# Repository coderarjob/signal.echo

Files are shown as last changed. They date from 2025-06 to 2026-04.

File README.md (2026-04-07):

<p align="center">
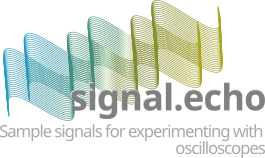
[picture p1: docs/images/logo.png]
    
    <br/>
    <br/>
    
    
</p>

## About

This is a hardware project based on Atmega8A microcontroller. This project came about from a
personal need for a demo board to test my new oscilloscope. I plan to create a complete PCB
along with firmware in this repo.

**Caution**: The `master` branch contains changes for the upcoming version and may not always be
stable. If you wish to manufacture, use the latest `release/version_x.x` branch or one of the
[released](https://github.com/coderarjob/signal.echo/releases) versions.

See [LICENCE](./LICENSE) for terms under which this project is released and developed.

### Screenshots

##### 1. Serial RS232 (TTL Level) decoding test

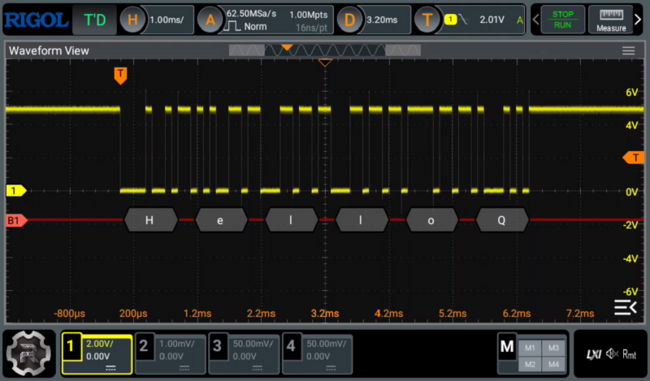
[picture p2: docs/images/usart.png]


##### 2. Serial I2C decoding test

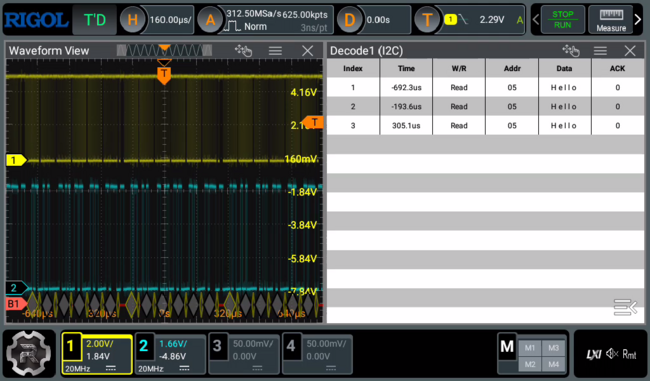
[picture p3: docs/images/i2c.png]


##### 3. Positive & negative Runt detection pulse

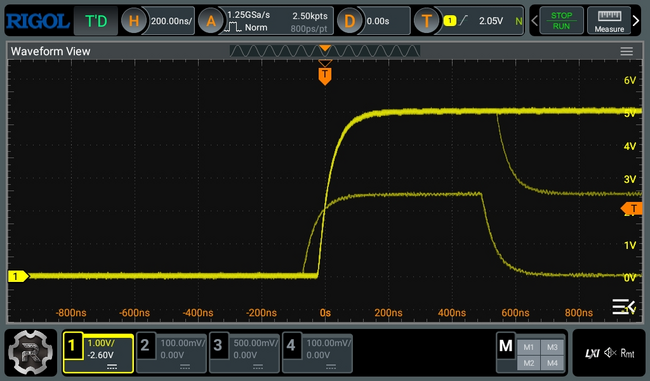
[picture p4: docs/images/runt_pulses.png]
Runt pulse


##### 4. Burst pulses (long delay)

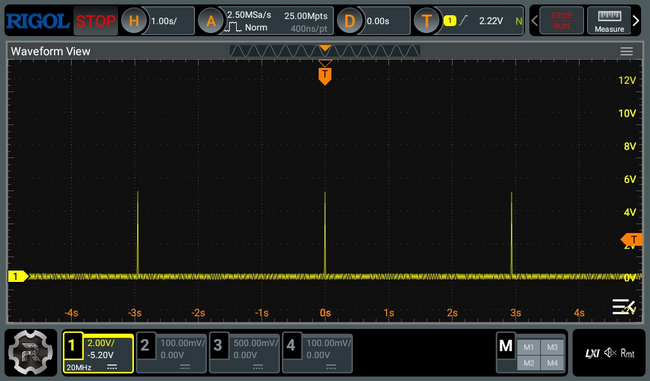
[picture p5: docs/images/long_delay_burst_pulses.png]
Burst pulse


##### 5. Two burst (time coorolated) pulses

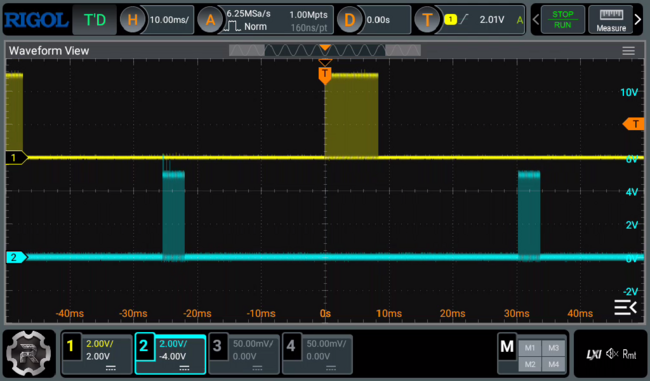
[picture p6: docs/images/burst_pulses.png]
two burst pulse


##### 6. Sine wave

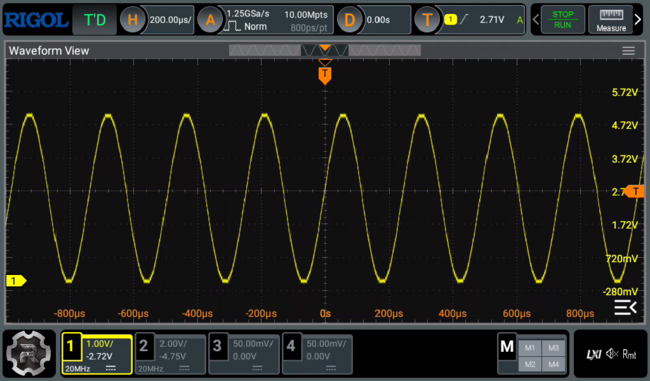
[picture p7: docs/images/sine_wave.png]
Sine wave

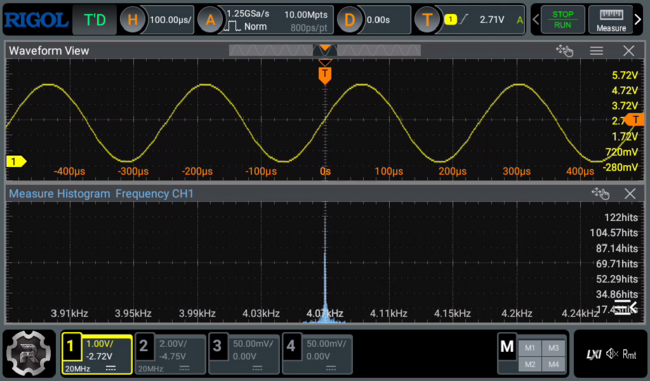
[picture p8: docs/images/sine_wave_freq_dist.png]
Sine wave

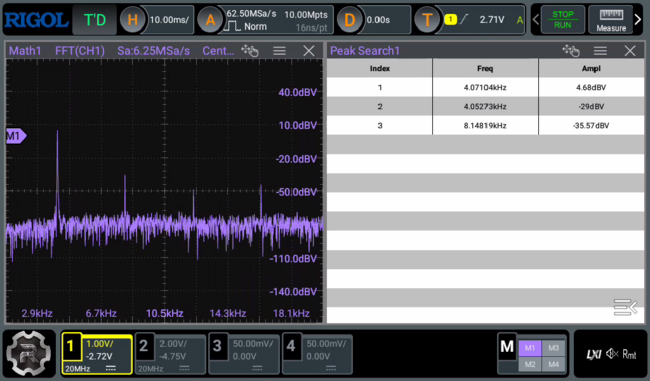
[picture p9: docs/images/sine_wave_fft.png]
Sine wave


##### 7. Amplitude Modulation wave

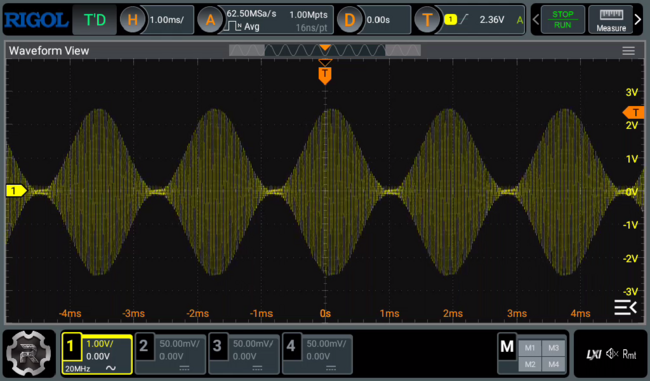
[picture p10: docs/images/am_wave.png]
Sine wave

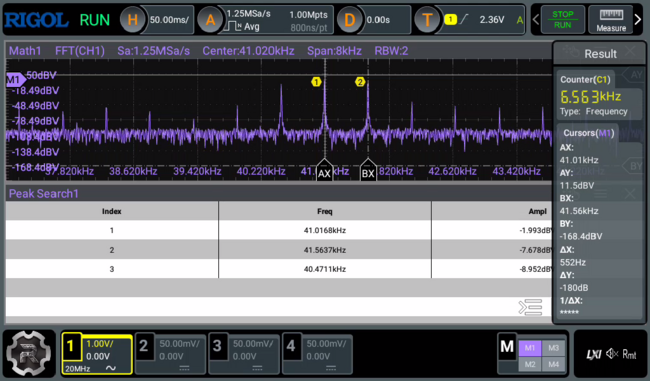
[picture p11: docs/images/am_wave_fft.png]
Sine wave


##### 8. Triangle wave

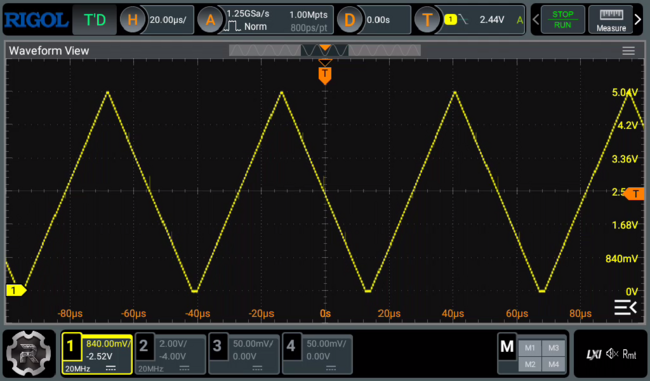
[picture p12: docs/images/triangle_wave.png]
Triangle wave

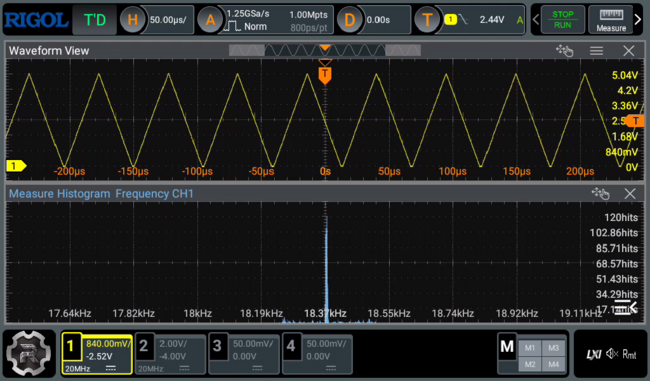
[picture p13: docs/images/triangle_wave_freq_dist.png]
Triangle wave

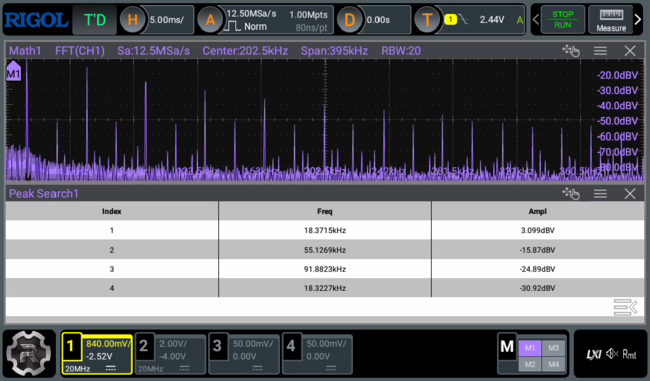
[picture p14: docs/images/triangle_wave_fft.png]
Triangle wave


##### 9. Sawtooth wave

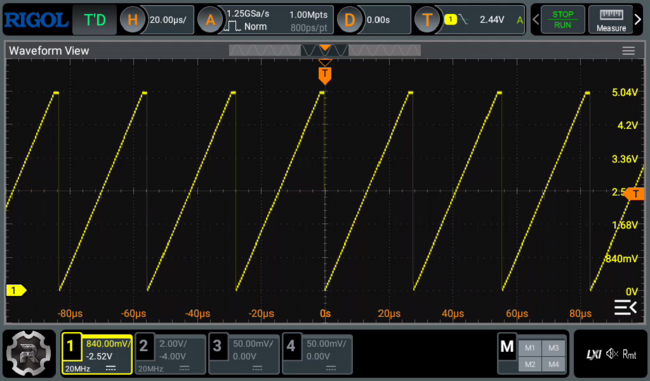
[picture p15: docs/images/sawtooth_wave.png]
Sawtooth wave

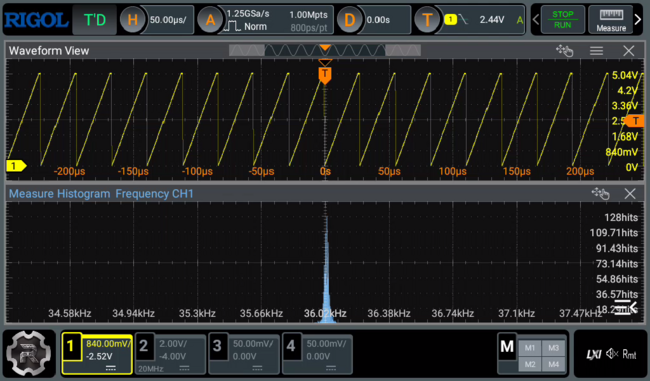
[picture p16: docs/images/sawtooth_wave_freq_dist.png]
Sawtooth wave

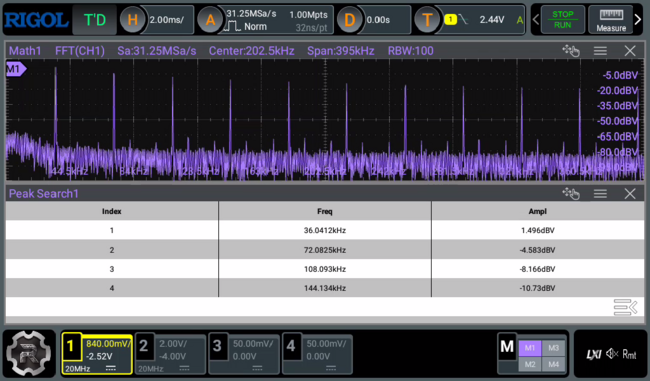
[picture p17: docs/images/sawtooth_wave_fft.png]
Sawtooth wave


### Goals

- [X] Firmware: RS232 sample output (positive)
- [X] Firmware: I2C sample output
- [X] Firmware: Runt pulse (+ve & -ve runt pulses)
- [X] Firmware: Sine wave pattern
- [X] Firmware: Amplitude Modulation wave pattern
- [X] Firmware: Triangle wave pattern
- [X] Firmware: Sawtooth wave pattern
- [X] Firmware: Burst data in two lines
- [X] Firmware: Separate arch independent codes
- [X] Unittests: Add unittests for utils
- [X] Unittests: Add unittests for existing tests
- [X] Manufacturing: Build the PCB board

## Building prerequisites

1. Requires Linux environment for building.
2. GNU Make
3. avr-gcc
4. avr-libc

### Firmware

Build the firmware using the following command. Firmware binary is the `./out/firmware.hex` file.

```bash
BUILD_DIR=out make
```

To program using avrdude we run the following command.

```bash
make program
```

When programming a new microcontroller, we also need to program the required fuse bits. This can be
using the following command

```bash
make program_fuses
```

### Unittests

We can build every unittests and run them using the `run` target.

```bash
BUILD=ut BUILD_DIR=out/ut make run
```

### Tools

Some tools which are used exclusively in this project are/will be put into the `tools` folder. Each
may have different prerequisites and build procedures. For information see `Readme.md` of each
tool.

# Feedback

Open a GitHub issue or drop a email at arjobmukherjee@gmail.com. I would love to hear your
suggestions and feedbacks.

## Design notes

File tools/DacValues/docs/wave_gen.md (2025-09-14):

##### 14-August-2025 19:44:42
# Generation of waves using DAC
##### Tags: electronics

The microcontoller is indexing into an array of values and writes them to DAC. The timing between
each writes is not controlled but can be taken as constant. Say the aray contains values that
represent one cycle of a sine wave. When these are written out, the frequency of the resulting
waveform will depend on two things:
1. `T` - The time spent by the microcontoller between writing two consecutive values to the DAC.
2. `N` - Number of values that represent the one cycle. If there are more number of points/values
   then it will take more time to dump the whole array to the DAC. Thus (frequency of the
   wave) `f ~ 1/(T * N)`.

The above relation of `f` & `N` means that a fast waveform requires less number of points but
also for the same reason will look bad because of the large quantization steps. This will be played
with depending on what waveform is generated.

All this happens in the microcontoller side and as you can see it just dumps data into the DAC and
does not control either the frequency or the look of it. Both depends on the how the values are
generated.

### Generation of DAC data - Sine wave

As stated above the DAC values given to the microcontoller represent one cycle of the required
waveform (one cycle all that is required because the waveform is repeating). If we want to increase
frequency, less points will represent that cycle, and a nicer looking waveform (but lower frequency)
will have more points for the same cycle.

Take the example of sine wave generation:

#### Algorithm

`sine(freq_scale, sample_count)` where 

* `freq_scale` - Number of generated points (samples) will be decreased to increase frequency by
  this amount
* `sample_count` - This many points will make one cycle of the repeating waveform, when `freq_scale`
  is 1.

```c
sine(freq_scale, sample_count) {
    // Time is incremented by this amount in each iteration.
    dt = freq_scale / sample_count
    
    // Since we stop iterating when time of 1.0 is reached, the number of samples that will be
    // in the output by then is 1/dt or `sample_count/freq_scale` number of points. That is as
    // `freq_scale` increases, N decreases and vice-versa.
    // Also note we have reached full cylcle (2 * PI radians) when time reached 1.0.
    N = 1/dt
    
    // Output list
    List(f64) output = empty;
    for (t = 0; t < 1.0; t += dt) {
        output.add(sin(2 * PI * t))
    }
    
    return output
}
```

#### Explanation

After `N = 1/dt` iterations, we will have `t = N * dt => t = dt/dt = 1`. In other words after `N`
iterations we have
* Number of cycles: 1
* Number of radians traversed: `2 * PI`.
* Number of sample points: `sample_count/freq_scale`.

So in the end, if `freq_scale` is 1, output represents one cycle and will have `sample_count` number
of points. If `freq_scale` is 2, output still will represent one cycle but now will have
`sample_count/2` number of points. Less number of points to equates to faster dump thus more
frequency.

##### Why not use `sin(2 * PI * freq_scale * t)` instead?

Lets do the same calculation as above. Since `freq_scale` now moved to the sine function, `dt`
becomes `dt = 1.0 / sample_count`. After `N = 1/dt` iterations, we will have `t = N * dt => t =
dt/dt = 1`. This remains the same, but the outcome is different. So  after `N` iterations we have
* Number of cycles: `freq_scale`. If it is 1, then 1 cycle, if its 2 then 2 cycles and so on.
* Number of radians traversed: `2 * PI * freq_scale`.
* Number of sample points: `sample_count`

So in the end, if `freq_scale` is 1, like before output represents one cycle and will have
`sample_count` number of points. If however `freq_scale` is 2, output will instead represent 2
cycles but will still have `sample_count` number of points. Same number of points representing more
number of cycles means less number of points per cycle and thus like before this equates to faster
dump thus more frequency.

So now that we know the difference between the two ways, the former method is chosen for generating
sine wave, since it always output one single cycle, which is what we want.

### Generation of DAC data - AM wave

Much of the things remain the same, however there are a few more parameters which we need to know
about. Lets recap the parameters which are common and the new ones

1. Number of sample points: `sample_count`
2. Number of cycles per envelop eye: $n = BASE\_FREQ * freq\_scale$. Where `BASE_FREQ` is any constant,
   currently its `50`.
3. Number of sample points per cycle: $S = sample\_count/n$. This many samples points will make up
   each cycle of the carrier wave. Larger `S` makes up for a smoother wave with less prominent
   steps. Note that this has nothing to do the DAC width. Its the number of sample points not the
   max value of it.

In order to control both the carrier frequency and the signal frequency a relation need to be made
between them and the number of sample points.

We know that the total number of samples (`sample_count`) determines the signal frequency, so it can
be said

* $sample\_count \propto t_m$ where $t_m$ is the time period of the signal wave.
* $sample\_count \propto n * t_c$ where $n$ is as defined above and $t_c$ is the time period of the
  carrier wave.
* Thus $t_m = n * t_c$ <br/>
  or ${t_m/t_c} = n$ <br/>
  or ${f_c/f_m} = n$ where $f_c$ & $f_m$ are carrier frequency & signal frequency respectively.

This above relation makes it possible to change one frequency by keeping the other fixed and varying
$n$. For example in order to increase the signal frequency for some carrier frequency, we have to
decreases $n$.

From a general understanding the following relation between the frequencies and sample count can be
established.

* $f_c \propto 1/S$. Less number of points in one cycle of the carrier wave, more it the resulting
  frequency of the wave. This implies the following
* $f_c \propto n$. Less number of cycles per envelop eye, more is the carrier frequency.
* $f_m \propto 1/sample\_count$. Less is the total number of points, more is the overall frequency
  and thus the envelop/signal frequency.

Now that the theory is done, lets look at the algorithm

#### Algorithm

`am(freq_scale, sample_count)` where 

* `freq_scale` - Used to calculate the number of complete cycles in one envelop eye ($n$ as above).
* `sample_count` - Total number of points in one envelop eye. Unlike the sine wave case here we will
  always produce this many samples irrespective of the `freq_scale` value.

```c
am(freq_scale, sample_count) {
    // Time is incremented by this amount in each iteration.
    // This implies that `sample_count` number of points will be in output when time of 1.0 is
    // reached (where we stop).
    dt = 1.0 / sample_count
    
    // BASE_FREQ is a constant. When freq_scale is 1, n = BASE_FREQ. That is when freq_scale = 1,
    // `BASE_FREQ` number of complete cycles (of carrier wave) will be outputted.
    BASE_FREQ = 50
    n = BASE_FREQ * freq_scale
    
    // Output list
    List(f64) output = empty;
    for (t = 0; t < 1.0; t += dt) {
        // * The 0.5 multiplication is to keep the result of the following equation between 0 and 1.
        //   Without it the output is between 0 and 2. See below
        // * Phase shift of (PI / 2) is applied just to reposition the generated wave. See below.
        output.add((1 + sin(2 * PI * t - (PI / 2)) * 0.5 * cos(2 * PI * t * n)
    }
    
    return output
}
```

The below image shows the modulated wave and the carrier wave.

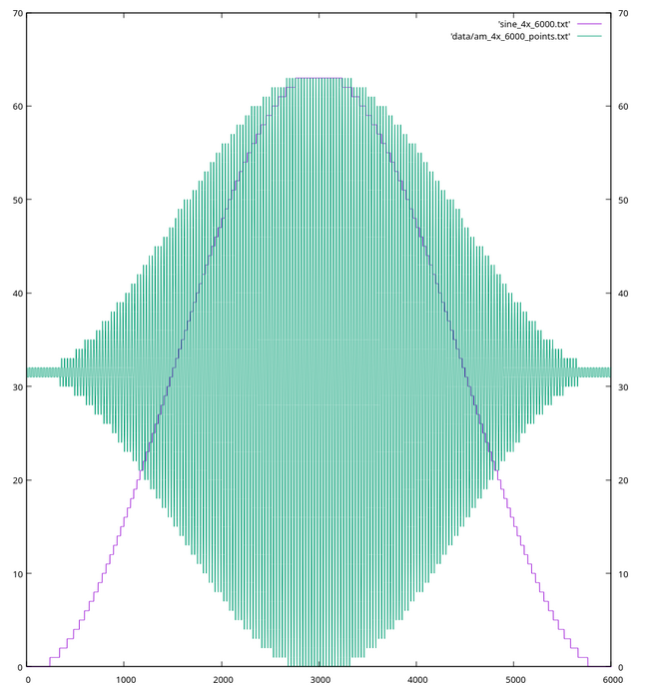
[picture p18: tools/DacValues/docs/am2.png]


* Note that one modulated eye is one full cycle of the signal not half cycle. Below image make it
  more clear.

For as an FYI the below image shows the same but without the phase shift of $\pi/2$ applied.
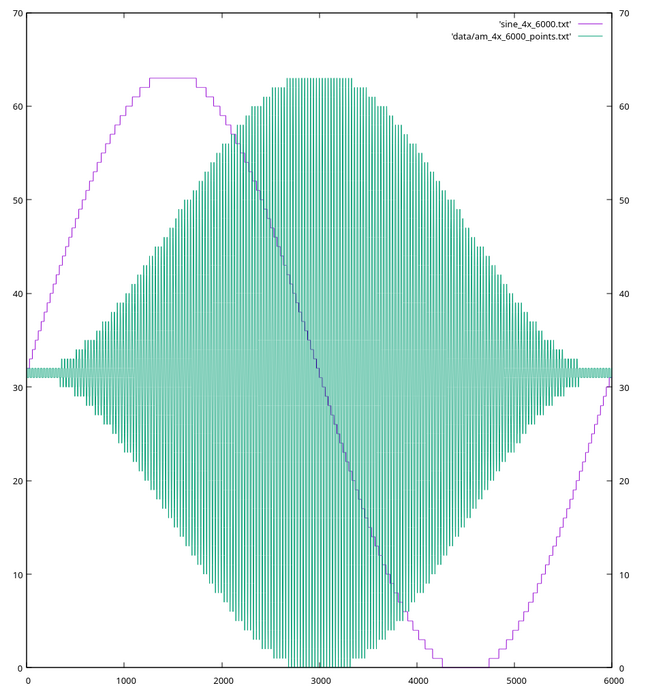
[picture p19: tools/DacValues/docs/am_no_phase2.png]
am_wave_with_phase_shift


#### Expectations

After `N = 1/dt` iterations, we will have `t = N * dt => t = dt/dt = 1`. In other words after `N`
iterations we have
* Number of cycles (signal wave): `1`
* Number of cycles (carrier wave) (`n`): `freq_scale * BASE_FREQ`
* Number of sample points: `sample_count`
* Number of samples per carrier wave cycle (`S`): $sample\_count/n$.

Note that this is exactly what other (alternate) method described in the Sine wave generation
section.

#### How to increase $f_m$ while keeping the $f_c$ and $S$ same?

Lets assume the following is AM wave we have currently:
```
* n             = 200. i.e freq_scale = 4 for BASE_FREQ = 50.
* fc / fm       = 200
* sample_count  = 6000
* S             = sample_count / n = 30

Actual frequency seen:
* fc = 41E3 Hz
* fm = 204  Hz
```

Now lets see what it takes to make systematic changes such as to increase the signal frequency while
keeping the look and feel same (carrier frequency and number of points per carrier wave cycle).

Its mentioned above that $f_m \propto 1/sample\_count$. Therefore to increase $f_m$, we have to
decrease $sample\_count$. However since $S = sample\_count/n$, in order to keep $S$ constant we have
to also decrease $n$.

Lets start by decreasing `n` first. Recall that `n` is the number of carrier cycles per envelop eye.
This will result in a higher `S`, so requires `sample_count` to also be lowered in order to keep `S`
constant.  Here `n` is decreased from 200 to 75. This is what is shown below.

```
* n            = 75 (our choice)
* S            = 30  (same as before)
* sample_count = S * n
               = 30 * 75 = 2250
* fc / fm      = 75 (from equation)
```

To generate the above/required AM wave we have call `am` function with the following parameters.
* `sample_count` = 2250
* `freq_scale`   = ${n \over BASE\_FREQ}$ = ${75 \over 50} = 1.5$.

```
Actual frequency seen

* fc = 41E3 Hz
* fm = 540  Hz
```

-------------------------

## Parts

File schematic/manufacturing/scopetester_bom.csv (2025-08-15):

Id | Designator | Footprint | Quantity | Designation | Supplier and ref
1 | J3 | PinHeader_2x05_P2.54mm_Vertical | 1 | AVR_ISP
2 | U1 | DIP-28_W7.62mm | 1 | ATmega8A-P
3 | C6,C7,C1,C2 | C_Disc_D3.0mm_W1.6mm_P2.50mm | 4 | 100nF
4 | JP1 | R_Axial_DIN0207_L6.3mm_D2.5mm_P7.62mm_Horizontal | 1 | Jumper_2_Bridged
5 | R8,R5,R9,R23,R12,R21,R18,R3,R6,R19,R16,R20,R7,R11,R14,R13,R15,R24,R4,R22,R2,R10,R17 | R_Axial_DIN0207_L6.3mm_D2.5mm_P7.62mm_Horizontal | 23 | 2.2k
6 | D1,D3,D4,D2 | LED_D3.0mm | 4 | LED_Small
7 | Y1 | Crystal_HC49-4H_Vertical | 1 | 16MHz
8 | SW1 | SW_PUSH_6mm_H4.3mm | 1 | SW_Push
9 | J2 | PinHeader_1x04_P2.54mm_Vertical | 1 | Conn_01x04
10 | C5 | CP_Radial_D5.0mm_P2.50mm | 1 | 1uF
11 | R1 | R_Axial_DIN0207_L6.3mm_D2.5mm_P7.62mm_Horizontal | 1 | 10k
12 | C4,C3 | C_Disc_D3.0mm_W1.6mm_P2.50mm | 2 | 22pF
13 | J1 | PinHeader_1x02_P2.54mm_Vertical | 1 | CON_PWR

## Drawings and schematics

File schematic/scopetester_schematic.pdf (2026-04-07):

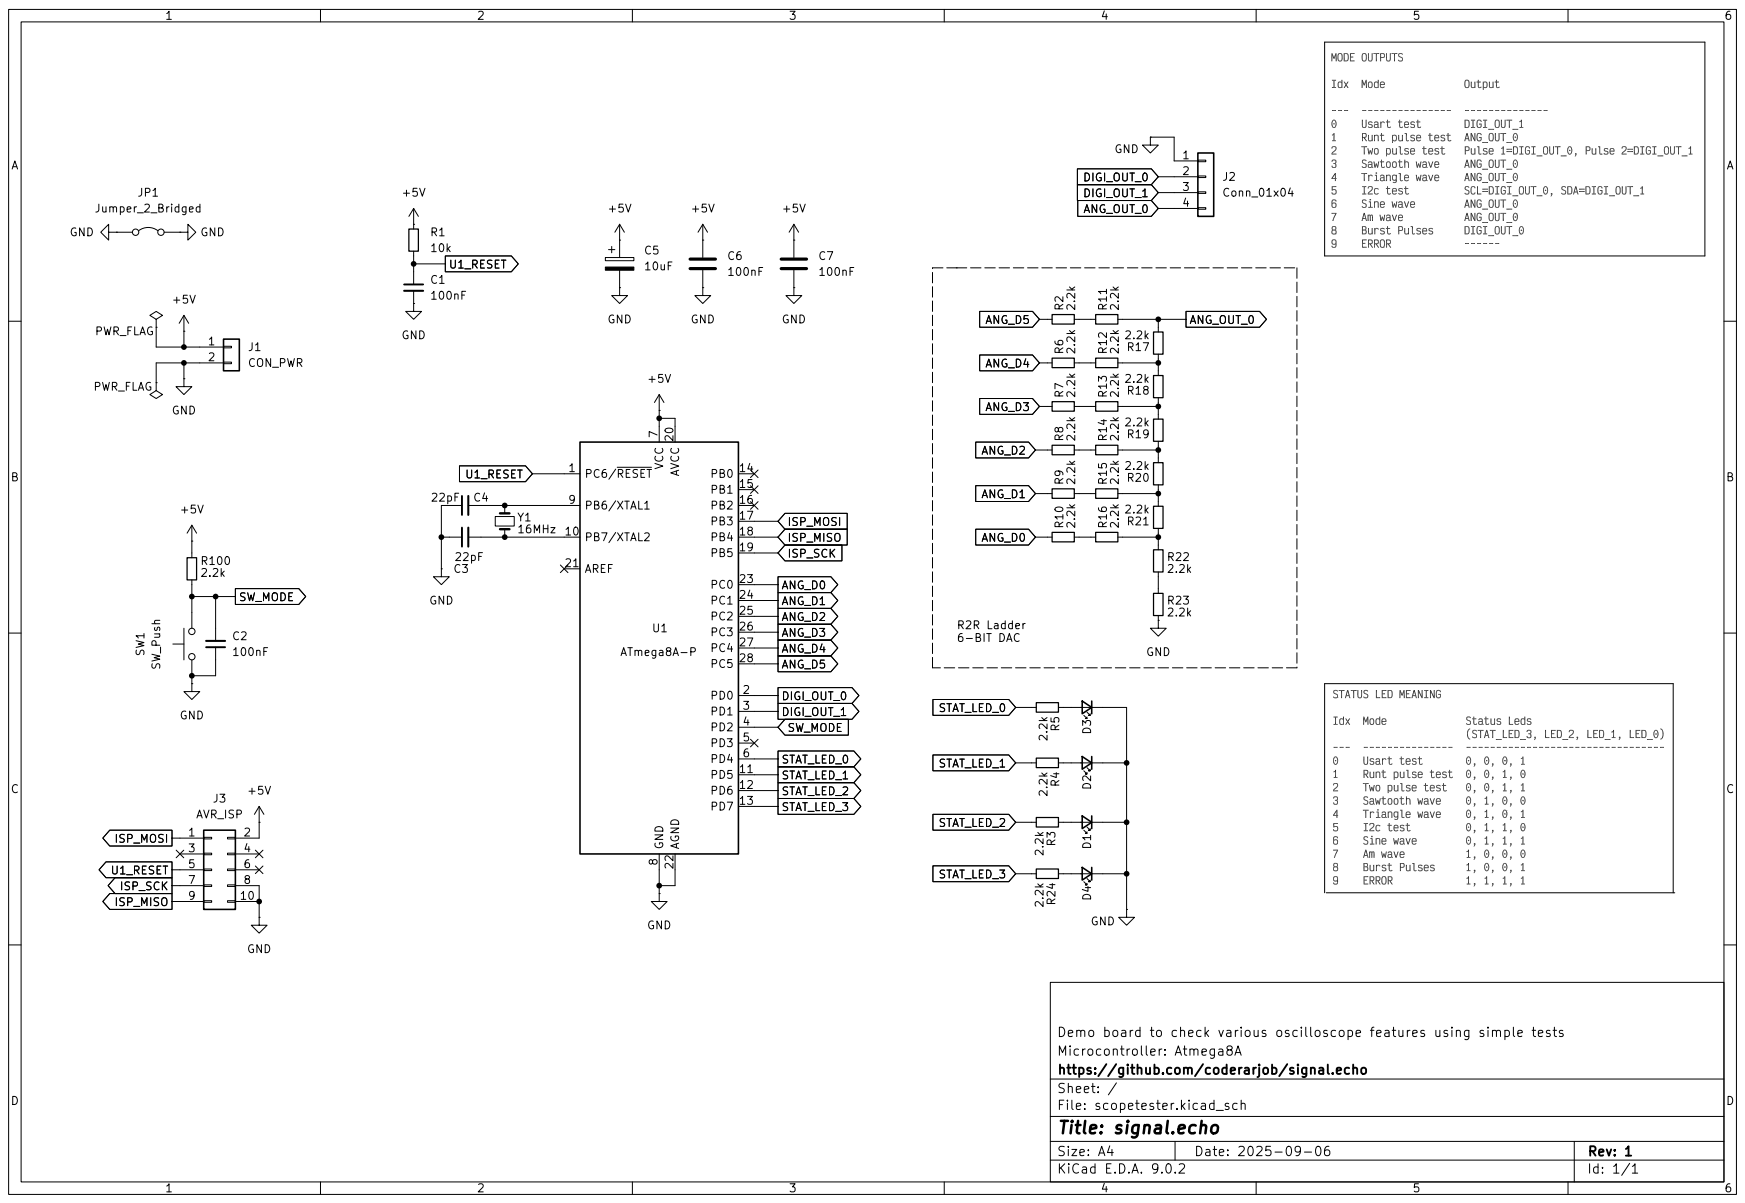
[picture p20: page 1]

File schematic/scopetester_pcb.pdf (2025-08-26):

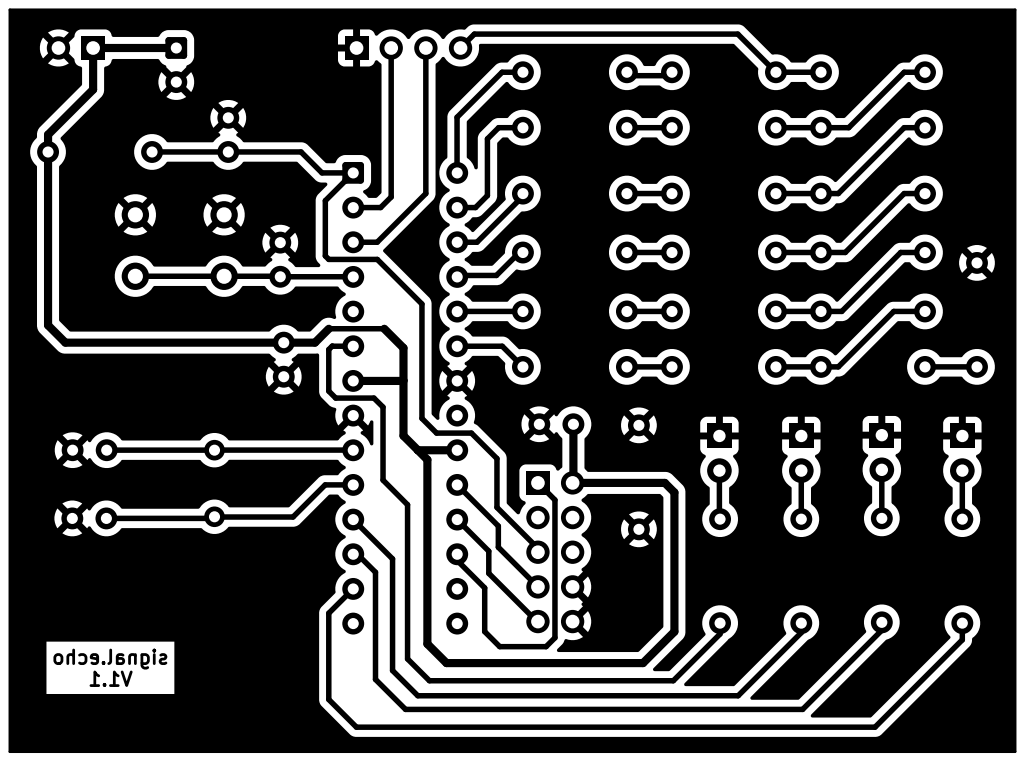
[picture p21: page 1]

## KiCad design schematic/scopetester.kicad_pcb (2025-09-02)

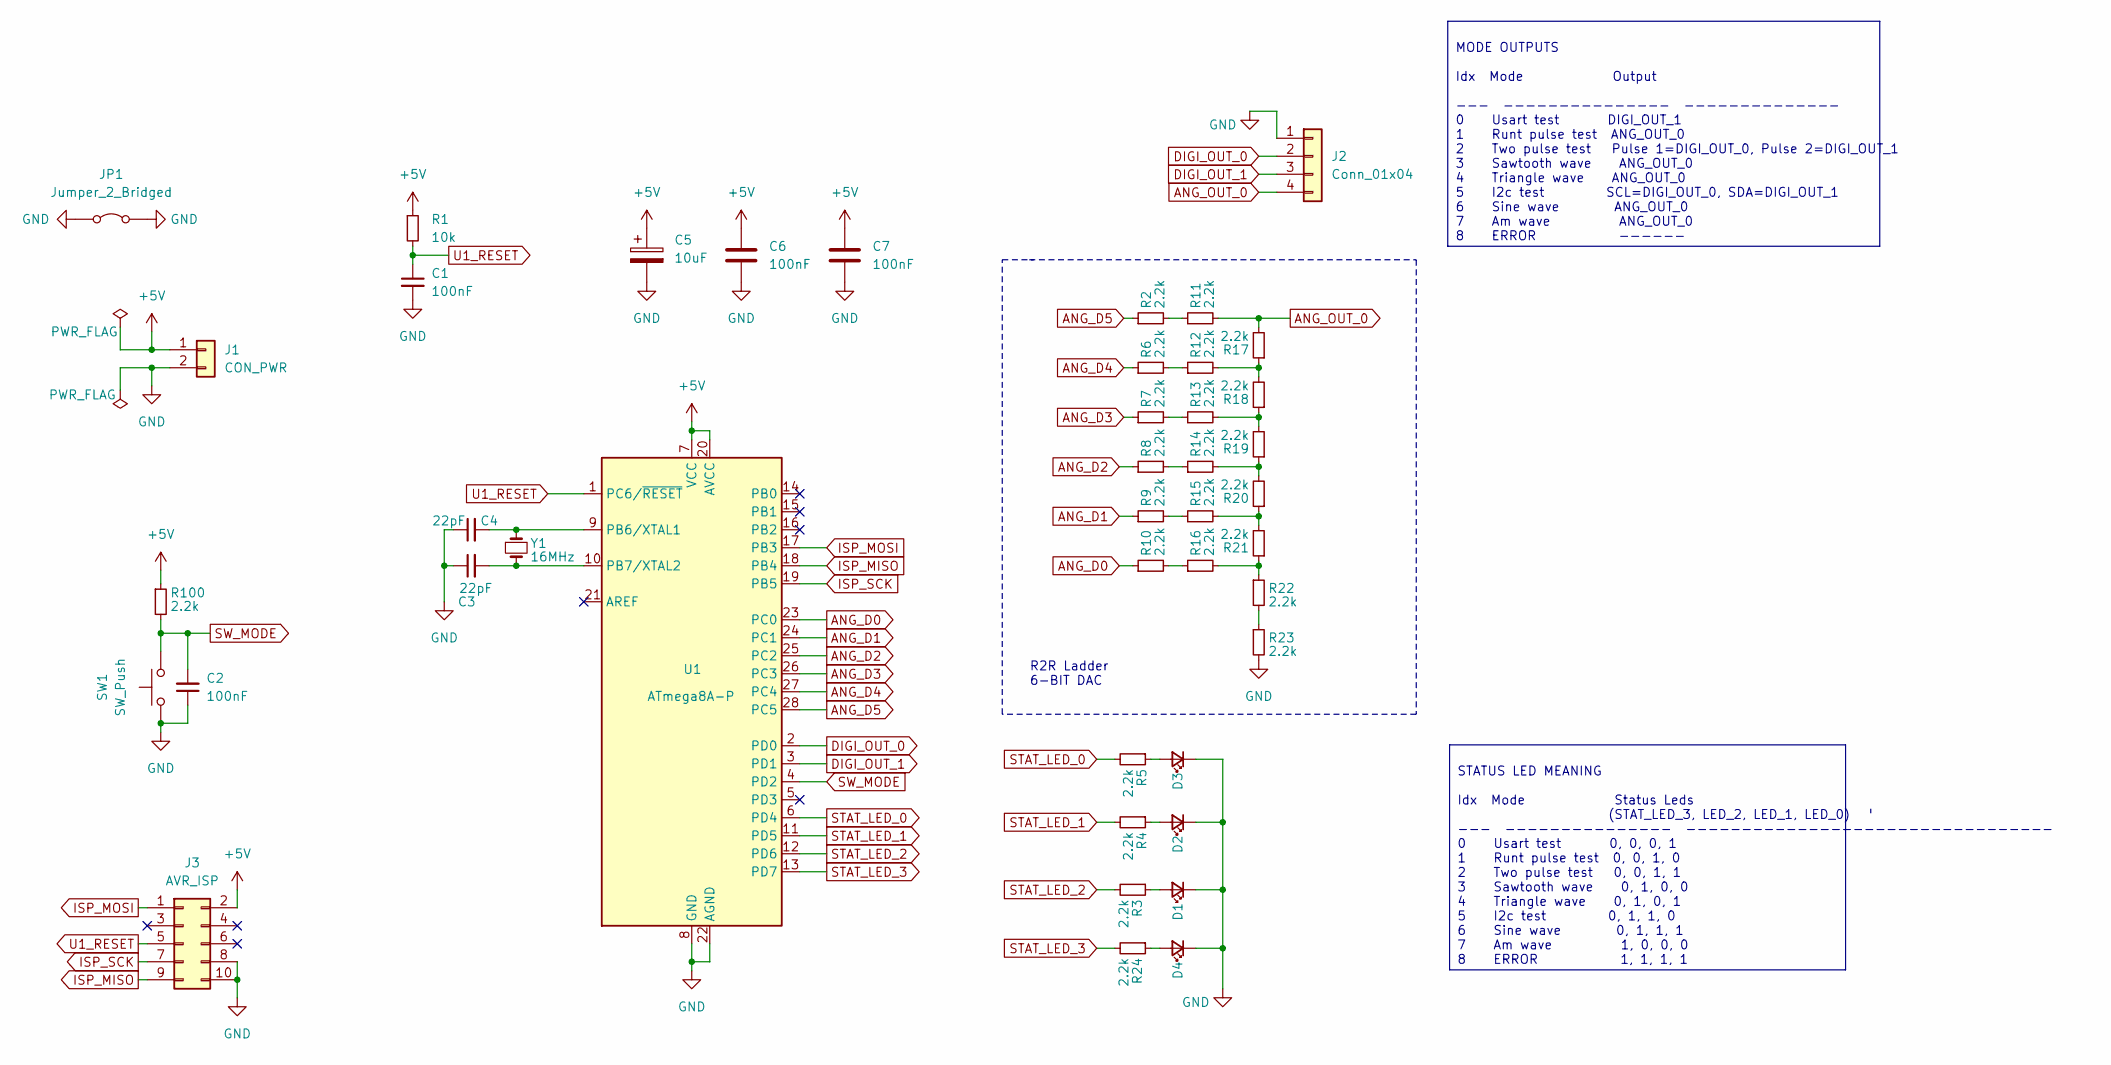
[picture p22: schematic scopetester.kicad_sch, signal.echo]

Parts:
C1, C2, C6, C7: 100nF; C_Disc_D3.0mm_W1.6mm_P2.50mm
C3, C4: 22pF; C_Disc_D3.0mm_W1.6mm_P2.50mm
C5: 10uF; CP_Radial_D5.0mm_P2.50mm
D1, D2, D3, D4: LED_Small; LED_D3.0mm
J1: CON_PWR; PinHeader_1x02_P2.54mm_Vertical
J2: Conn_01x04; PinHeader_1x04_P2.54mm_Vertical
J3: AVR_ISP; PinHeader_2x05_P2.54mm_Vertical
JP1: Jumper_2_Bridged; R_Axial_DIN0207_L6.3mm_D2.5mm_P7.62mm_Horizontal
R1: 10k; R_Axial_DIN0207_L6.3mm_D2.5mm_P7.62mm_Horizontal
R2, R3, R4, R5, R6, R7, R8, R9, R10, R11, R12, R13, R14, R15, R16, R17, R18, R19, R20, R21, R22, R23, R24: 2.2k; R_Axial_DIN0207_L6.3mm_D2.5mm_P7.62mm_Horizontal
R100: 2.2k; R_Axial_DIN0411_L9.9mm_D3.6mm_P5.08mm_Vertical
SW1: SW_Push; SW_PUSH_6mm_H4.3mm
U1: ATmega8A-P; DIP-28_W7.62mm
Y1: 16MHz; Crystal_HC49-4H_Vertical

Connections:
+5V: C5.1, C6.1, C7.1, J1.1, J3.2, R1.1, R100.1, U1.7 (VCC), U1.20 (AVCC)
ANG_D0: R10.1, U1.23 (PC0)
ANG_D1: R9.1, U1.24 (PC1)
ANG_D2: R8.1, U1.25 (PC2)
ANG_D3: R7.1, U1.26 (PC3)
ANG_D4: R6.1, U1.27 (PC4)
ANG_D5: R2.1, U1.28 (PC5)
ANG_OUT_0: J2.4, R11.2, R17.2
DIGI_OUT_0: J2.2, U1.2 (PD0)
DIGI_OUT_1: J2.3, U1.3 (PD1)
GND: C1.2, C2.1, C3.1, C4.1, C5.2, C6.2, C7.2, D1.1 (K), D2.1 (K), D3.1 (K), D4.1 (K), J1.2, J2.1, J3.8, J3.10, JP1.1 (A), JP1.2 (B), R23.2, SW1.1, U1.8 (GND), U1.22 (AGND)
ISP_MISO: J3.9, U1.18 (PB4)
ISP_MOSI: J3.1, U1.17 (PB3)
ISP_SCK: J3.7, U1.19 (PB5)
unnamed: D1.2 (A), R3.1
unnamed: D2.2 (A), R4.1
unnamed: D3.2 (A), R5.1
unnamed: D4.2 (A), R24.1
unnamed: R10.2, R16.1
unnamed: R2.2, R11.1
unnamed: R6.2, R12.1
unnamed: R12.2, R17.1, R18.2
unnamed: R7.2, R13.1
unnamed: R13.2, R18.1, R19.2
unnamed: R8.2, R14.1
unnamed: R14.2, R19.1, R20.2
unnamed: R9.2, R15.1
unnamed: R15.2, R20.1, R21.2
unnamed: R16.2, R21.1, R22.1
unnamed: R22.2, R23.1
unnamed: C4.2, U1.9 (PB6/XTAL1), Y1.1
unnamed: C3.2, U1.10 (PB7/XTAL2), Y1.2
STAT_LED_0: R5.2, U1.6 (PD4)
STAT_LED_1: R4.2, U1.11 (PD5)
STAT_LED_2: R3.2, U1.12 (PD6)
STAT_LED_3: R24.2, U1.13 (PD7)
SW_MODE: C2.2, R100.2, SW1.2, U1.4 (PD2)
U1_RESET: C1.1, J3.5, R1.2, U1.1 (PC6/~RESET)

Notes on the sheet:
R2R Ladder 6-BIT DAC
MODE OUTPUTS Idx Mode Output --- --------------- -------------- 0 Usart test DIGI_OUT_1 1 Runt pulse test ANG_OUT_0 2 Two pulse test Pulse 1=DIGI_OUT_0, Pulse 2=DIGI_OUT_1 3 Sawtooth wave ANG_OUT_0 4 Triangle wave ANG_OUT_0 5 I2c test SCL=DIGI_OUT_0, SDA=DIGI_OUT_1 6 Sine wave ANG_OUT_0 7 Am wave A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
STATUS LED MEANING Idx Mode Status Leds (STAT_LED_3, LED_2, LED_1, LED_0) --- --------------- --------------------------------- 0 Usart test 0, 0, 0, 1 1 Runt pulse test 0, 0, 1, 0 2 Two pulse test 0, 0, 1, 1 3 Sawtooth wave 0, 1, 0, 0 4 Triangle wave 0, 1, 0, 1 5 I2c test 0, 1, 1, 0 6 Sine wave 0,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

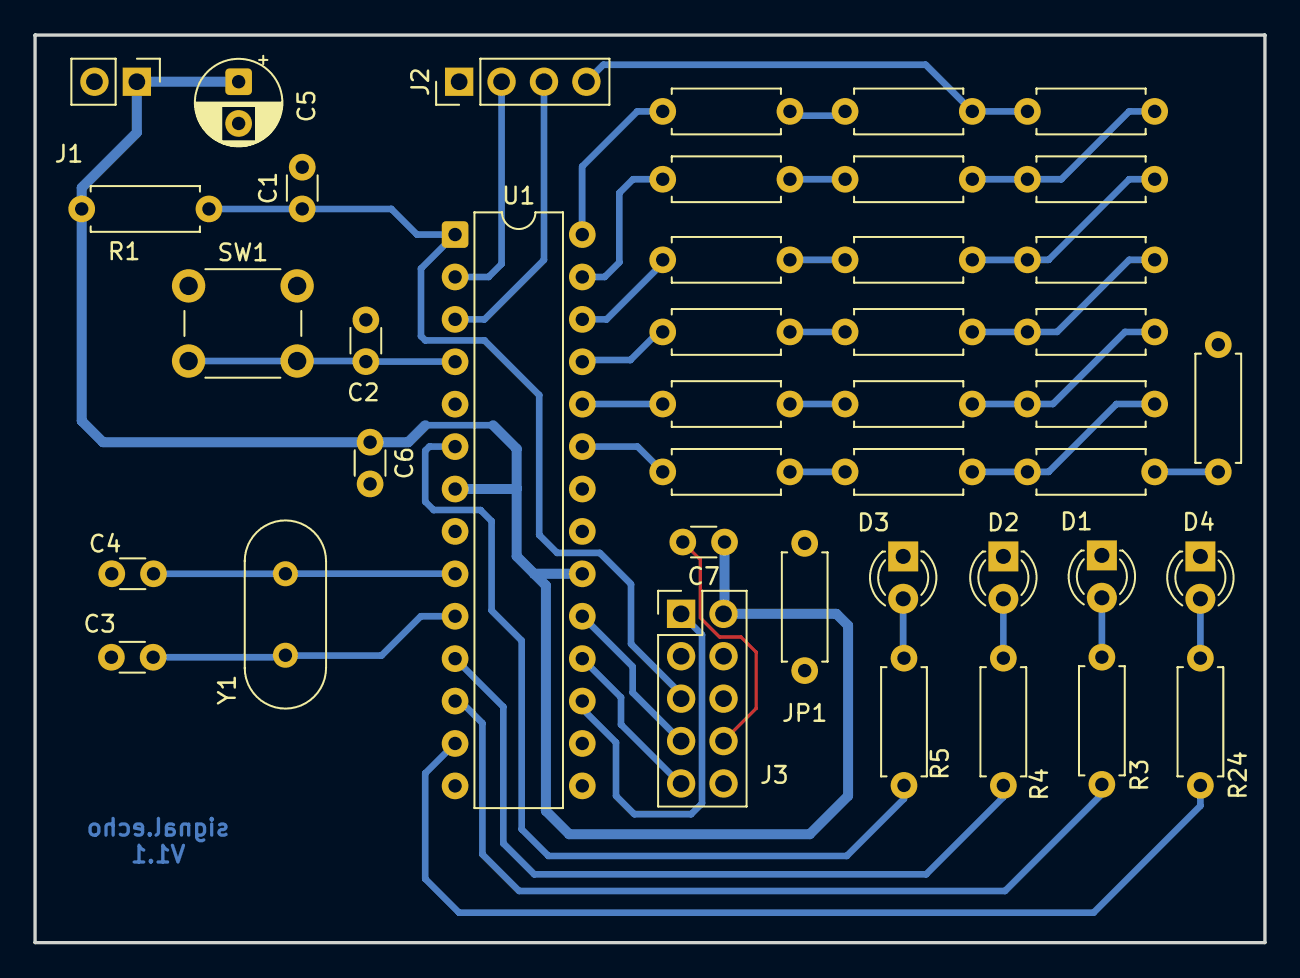
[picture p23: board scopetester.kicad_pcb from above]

Board: 2 copper layers, 73.7 x 54.4 mm, 42 parts (0 on the bottom side), 38 nets.

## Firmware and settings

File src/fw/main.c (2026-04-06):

#include <hal.h>
#include <hw/hwspec.h>
#include <hw/hwdetect.h>
#include <main.h>

#if defined(DEBUG)
    #include <static_assert.h>
void hwspec_sanity_check()
{
    #if ARCH == AVR && SWITCH_INPUT_GPIO_PIN != PD2
        #error "Wrong switch pin set"
    #endif

    #define CHECK_OVERLAP(comb, mask) (((comb) & (mask)) != (mask))

    // Port A checks
    // N/A

    // Port D checks
    // N/A

    // Port B
    #define GPIO_B_COMB                                                                         \
        (SWITCH_INPUT_PIN_MASK ^ STATUS_OUTPUT_PIN_MASK ^ TWO_PULSES_TEST_OUTPUT_PIN_NO0_MASK ^ \
         TWO_PULSES_TEST_OUTPUT_PIN_NO1_MASK)

    #if CHECK_OVERLAP(GPIO_B_COMB, SWITCH_INPUT_PIN_MASK) ||               \
        CHECK_OVERLAP(GPIO_B_COMB, STATUS_OUTPUT_PIN_MASK) ||              \
        CHECK_OVERLAP(GPIO_B_COMB, TWO_PULSES_TEST_OUTPUT_PIN_NO0_MASK) || \
        CHECK_OVERLAP(GPIO_B_COMB, TWO_PULSES_TEST_OUTPUT_PIN_NO1_MASK)
        #error "GPIO_B pin overlapped"
    #endif // GPIO_B_COMB checks

    // Port C
    #define GPIO_C_COMB (RUNT_PULSE_TEST_OUTPUT_PIN_MASK)

    #if CHECK_OVERLAP(GPIO_C_COMB, RUNT_PULSE_TEST_OUTPUT_PIN_MASK)
        #error "GPIO_C pin overlapped"
    #endif // GPIO_C_COMB checks

    // Mode count must not exceed the number of displayable states in hw
    STATIC_ASSERT (TEST_MODE_ERROR == ((1 << STATUS_OUTPUT_PIN_COUNT) - 1));
    STATIC_ASSERT (TEST_MODE_COUNT < TEST_MODE_ERROR);
}
#endif // defined(DEBUG)

void hw_init()
{
    // ===========================================
    // Outputs
    // Make digital, analog and status led pins as output and clear them
    // ===========================================
    HAL_IO_MAKE_OUTPUT (DIGITAL_OUTPUT_GPIO, DIGITAL_OUTPUT_PIN_MASK);
    HAL_IO_OUT_LOW (DIGITAL_OUTPUT_GPIO, DIGITAL_OUTPUT_PIN_MASK);

    HAL_IO_MAKE_OUTPUT (ANALOG_OUTPUT_GPIO, ANALOG_OUTPUT_PIN_MASK);
    HAL_IO_OUT_LOW (ANALOG_OUTPUT_GPIO, ANALOG_OUTPUT_PIN_MASK);

    HAL_IO_MAKE_OUTPUT (STATUS_OUTPUT_GPIO, STATUS_OUTPUT_PIN_MASK);
    HAL_IO_OUT_LOW (STATUS_OUTPUT_GPIO, STATUS_OUTPUT_PIN_MASK);

    // ===========================================
    // Inputs
    // Make switch pin as input and enable pullup
    // ===========================================
    HAL_IO_MAKE_INPUT_WITH_PULLUP (SWITCH_INPUT_GPIO, SWITCH_INPUT_PIN_MASK);
    hal_interrupt_enable (SWITCH_INPUT_INTERRUPT);

    HAL_INTERRUPT_SET();

    // ===========================================
    // IO & Schematic sanity check
    // ===========================================
#if defined(DEBUG)
    hwspec_sanity_check();
#endif
}

static inline void set_status_led (uint8_t state)
{
    HAL_IO_OUT_WRITE_BITS (STATUS_OUTPUT_GPIO, MODE_LED_VALUE_FROM_TESTMODE (state),
                           STATUS_OUTPUT_PIN_SHIFT, STATUS_OUTPUT_PIN_MASK);
}

NORETURN void fw_main (void)
{
    hw_init();
    mode_reset();

#if !defined(UNITTESTS)
    while (1)
#endif // !defined(UNITTESTS)
    {
        set_status_led (mode_get());
        switch (mode_get()) {
        case TEST_MODE_USART_TEST:
            usart_test();
            break;
        case TEST_MODE_RUNT_PULSE_TEST:
            runt_pulse_test();
            break;
        case TEST_MODE_TWO_PULSES_TEST:
            two_pulses_test();
            break;
        case TEST_MODE_SAWTOOTH_TEST:
            sawtooth_test();
            break;
        case TEST_MODE_TRIANGLE_TEST:
            triangle_test();
            break;
        case TEST_MODE_I2C_TEST:
            i2c_test();
            break;
        case TEST_MODE_SINE_TEST:
            sine_test();
            break;
        case TEST_MODE_AMP_MOD_TEST:
            am_test();
            break;
        case TEST_MODE_BURST_PULSES:
            burst_pulses_test();
            break;
        default:
            hal_impl_panic();
            break;
        }
    }
}

#if !defined(UNITTESTS)
__attribute__ ((noreturn)) int main (void)
{
    fw_main();
}
#endif // !defined(UNITTESTS)

#if !defined(UNITTESTS)
void hal_impl_panic()
{
    set_status_led (TEST_MODE_ERROR);
    while (1)
        ;
}
#endif

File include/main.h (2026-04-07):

#pragma once

#include <stdbool.h>
#include <hw/hwspec.h>

#if !defined(UNITTESTS)
    #define NORETURN __attribute__ ((noreturn))
#else
    #define NORETURN
#endif // !defined(UNITTESTS)

#define USART_TEST_DELAY_LOOP_COUNT             65535U
#define USART_TEST_STRING                       "Hello"

#define RUNT_PULSE_FREQ                          1000 // 1 runt pulse after this many pulses
#define RUNT_TEST_RUNT_PULSE_WIDTH_LOOP_COUNT    2U
#define RUNT_TEST_NORMAL_PULSE_WIDTH_LOOP_COUNT  512U

#define RUNT_TEST_RUNT_HIGH_LEVEL               ((DAC_WIDTH_MAX_VALUE / 2) - 1)
#define RUNT_TEST_RUNT_LOW_LEVEL                ((DAC_WIDTH_MAX_VALUE / 2) - 1)
#define RUNT_TEST_NORMAL_HIGH_LEVEL             (DAC_WIDTH_MAX_VALUE - 1)
#define RUNT_TEST_NORMAL_LOW_LEVEL              0x00U // 0x0 is full rail low

#define TWO_PULSES_TEST_NUMBER_OF_PULSES_PIN0   150U
#define TWO_PULSES_TEST_NUMBER_OF_PULSES_PIN1   300U
#define TWO_PULSES_TEST_DELAY_LOOP_COUNT        65535U
#define TWO_PULSES_TEST_PULSE_WIDTH             23U

#define SAWTOOTH_TEST_HIGH_LEVEL                (DAC_WIDTH_MAX_VALUE - 1)
#define SAWTOOTH_TEST_LOW_LEVEL                 0x00
#define SAWTOOTH_TEST_INCREMENT                 0x01

#define TRIANGLE_TEST_HIGH_LEVEL                (DAC_WIDTH_MAX_VALUE - 1)
#define TRIANGLE_TEST_LOW_LEVEL                 0x00
#define TRIANGLE_TEST_INCREMENT                 0x01

#define I2C_TEST_SCL_HOLD_DELAY                 10
#define I2C_TEST_STRING                         "Hello"

#define BURST_PULSES_TEST_MAX_NUMBER_OF_PULSES   4U
#define BURST_PULSES_TEST_PULSE_DELAY_LOOP_CONT  20U
// Total delay bettween bursts is DELAY0_LOOP_CONT * DELAY1_LOOP_CONT
#define BURST_PULSES_TEST_BURST_DELAY0_LOOP_CONT 65535U
#define BURST_PULSES_TEST_BURST_DELAY1_LOOP_CONT 180U

#define MODE_LED_VALUE_FROM_TESTMODE(state)     ((state) != TEST_MODE_ERROR ? (state) + 1 : (state))

typedef enum TestModes {
    TEST_MODE_USART_TEST      = 0,
    TEST_MODE_RUNT_PULSE_TEST = 1,
    TEST_MODE_TWO_PULSES_TEST = 2,
    TEST_MODE_SAWTOOTH_TEST   = 3,
    TEST_MODE_TRIANGLE_TEST   = 4,
    TEST_MODE_I2C_TEST        = 5,
    TEST_MODE_SINE_TEST       = 6,
    TEST_MODE_AMP_MOD_TEST    = 7,
    TEST_MODE_BURST_PULSES    = 8,
    TEST_MODE_COUNT,
    TEST_MODE_ERROR = 15
} TestModes;

void mode_advance();
TestModes mode_get();
bool mode_is_dirty();
void mode_reset();

void usart_test();
void runt_pulse_test();
void two_pulses_test();
void sawtooth_test();
void triangle_test();
void i2c_test();
void sine_test();
void am_test();
void burst_pulses_test();

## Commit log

2025-06-05 Minor fixes and cleanup
    * src/fw/arch/avr/io.c, src/fw/arch/avr/main.c were unused
    * Phony target was wrong in Makefile
    [main.c]
2025-06-05 Fix: Usart sending wrong first character
    [main.c]
2025-06-05 Fix: Runt pulse was generated continuously
    [main.c]
2025-06-05 New usart_test_reset_after_char_overflow test
    Also includes:
    * Minor fixes to other tests.
    [feature_test.c]
2025-06-05 reset_all_mocks() to reset all mock functions
    [feature_test.c]
2025-06-07 Minor fixes to compiler warning during Unittest build
    [main.h]
2025-06-09 Fix: Current Mode is unknwon state at startup
    [main.c, main.h]
2025-06-15 DIGITAL_OUTPUT_PIN_NO0 is now PD0 not PD1
    This aligns with schematic and common sense!
2025-06-15 3 LED's now show current mode
2025-06-15 Fix: Switch debouncing
2025-06-15 Added schematic diagram for the project
    [scopetester_v1.kicad_pcb, scopetester_v1.kicad_sch]
2025-06-17 Minor updates, makes DAC clear & change of title
    [scopetester_v1.kicad_sch]
2025-06-20 Using HAL to simplify firmware source code (UT failing)
    * HAL is the only arch dependent code. Tests and even HW initialization
    are done in arch/hw schematic independent way.
    * HW has its versions & is defined in include/hw/<ver>/hwspec.h file.
    [hwspec.h, main.c, main.h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]
2025-06-21 hwspec.h should only reference arch independent types
    Otherwise it becomes difficult to unittest with a arch independent
    mocked hal.
    Fixed for AVR_HAL_INTERRUPTS_EXT_INTERRUPT0 which was referenced from
    hwspec.h.
    [hal.c, hal.h, hwspec.h]
2025-06-21 Fix: two_pulses_test used wrong mask for output gpio
    [tests.c]
2025-06-21 Fix: Baud counter calculation fixed in AVR HAL
    [hal.h]
2025-06-22 Increase freq of Triangle & Sawtooth waves
    ```
    Triangle Sawtooth
    Previous 03.89 kHz 10.39 kHz
    Current 18.37 kHz 36.02 kHz
    ```
2025-06-25 I2C test added
    Bit banging i2c implementation was added. It sends I2C packet with
    address & data bytes.
    * Screenshot & Readme update
    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
2025-06-26 Modes updated in schematic & initial PCB layout
    [scopetester_v1.kicad_pcb, scopetester_v1.kicad_sch]
2025-06-27 Update yukti.h to latest
    Commit ID: e8a1000
    Fix: Valgrind 'Uninitialised memory access' error
    * Corresponding unittest changes.
    * 'BUILD=ut make run' now stops at the first failed test.
    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
    [feature_test.c, hal_test.c]
2025-06-28 Status LED out derived from current TestMode
    Previously they were 1:1 mapped.
2025-06-29 Fix: YUKTI_TEST_IMPLEMENTATION not working
    This happens if yukti.h is included from from another header - (for
    example from a mock header) before the YUKTI_TEST_IMPLEMENTATION is
    defined in the test source file.
    One solution is to define YUKTI_TEST_IMPLEMENTATION and include yukti.h
    in the first line in test source.
    [feature_test.c, fwmain_test.c, hal_test.c]
2025-07-02 There are now 4 status LEDs instead of 3
    [scopetester_v1.kicad_sch]
2025-07-02 Fix: Sine wave shape
    [tests.c]
2025-07-04 Sine wave data is put on the .data section explicitly
    This produces same assembly expect for one LDI instruction within the
    loop, related to the 'for' loop in sine_test function. This extra
    instruction causes little dip in the output freq, but is otherwise same.
2025-07-04 Added Timer0 interrupt to avr/hal
2025-07-04 Cleanup HAL mock. Now contained in hal_mock.h
    * mock/hal.h contains mocked macro definitions for the firmware (during
    unittest builds). It replaces arch specific hal.h in the firmware
    sources.
    * mock/hal_mock.h contains mocked implementation of arch independent HAL
    functions to be used in unittests.
    [hal.h]
2025-07-05 Replaced Vcc with +5V in schematic
    [scopetester_v1.kicad_pcb, scopetester_v1.kicad_sch]
2025-07-06 Fix: More proper footprints instead of guessing
    [scopetester_v1.kicad_sch]
2025-07-06 Initial commit for PCB layout
    [scopetester_v1.kicad_pcb, scopetester_v1.kicad_sch]
2025-07-08 Multiple fixes to PCB layout (not final)
    [scopetester_v1.kicad_pcb, scopetester_v1.kicad_sch]
2025-07-09 More compact PCB layout
    [scopetester_v1.kicad_pcb, scopetester_v1.kicad_sch]
2025-07-09 Finalized PCB layout (edition 1)
    The DRC error of 'mission connection between items' was solved using a
    phony track on the front side. This is just to satisfy KiCad because it
    does not seem to understand that jumper is actually bridged.
    [scopetester_v1.kicad_pcb, scopetester_v1.kicad_sch]
2025-07-17 Now using 16MHz clock instead of 12MHz
    This increases the waveform frequencies by 33.3%.
    [scopetester_v1.kicad_pcb, scopetester_v1.kicad_sch]
2025-07-17 Fix: ifdef guards for MPU_ARCH were always passing
    Also fixes, `MPU_ARCH` value passed during unittests build was different
    than what was passed when building firmware.
    [main.c, tests.c]
2025-07-17 hal_impl_panic is fully mocked for unittest
    * Fixes compiler warning during unittest 'noreturn function returning'.
    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
    [fwmain_test.c, hal.h, main.c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]
2025-07-17 Update yukti.h to latest
    Commit ID: 95cb810
    Fix: Compiler warnings & build failures
    * Fixes warning for printf formatting mismatch for long integers.
    * ut_equal_mem & ut_equal_string functions undefined error.
2025-08-02 Simplify String to enum conversion & Usage printing
2025-08-10 Update kicad Project to Kicad-9
    [scopetester_v1.kicad_pcb, scopetester_v1.kicad_sch]
2025-08-13 Fix: Unittest build failure after d8fdfe4
    [fwmain_test.c]
2025-08-15 Minor changes to comments in schematic
    [scopetester_v1.kicad_sch]
2025-08-15 Added GBR and BOM files
    [scopetester_v1.kicad_pcb, scopetester_v1_bom.csv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]
2025-08-17 Made tracks bit thicker & fixed few DRC warnings
    [scopetester_v1.kicad_pcb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]
2025-08-25 Minor updates to PCB layout
    * Cap C5 changes to 10uF from 1uF
    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
    [scopetester_v1.kicad_pcb, scopetester_v1.kicad_sch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]
2025-08-26 PCB changes to make layout less dense
    [scopetester_v1.kicad_pcb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]
2025-08-26 Minor changes, project name & version update
    [scopetester_v1.kicad_pcb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]
2025-09-02 Adds GBR files B_Mask and F_Fab layers
    [scopetester_v1.kicad_pcb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]
2025-09-05 Remove 'In Development' message after the latest PCB working
2025-09-06 hw: Added info about outputs depending on modes
    * Title update in the schematic. ScopeTester -> signal.echo.
    * GitHub repo link added to schematic description.
    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
    [scopetester_v1.kicad_sch]
2025-09-07 Remove '_v1' from schematic files names
    See previous commit for reason.
    [scopetester.kicad_pcb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]
2025-09-07 New make target to program fuses bits
    * Corresponding documentation update
    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
2025-09-14 Fix: Wrongly generated AM wave
    The AM wave gen calculation was wrong resulting is wrong frequency
    components, which can be seen in the FFT and also just at looking at the
    shape of the wave.
    Multiple changes were done surrounding this fix.
    * tools/DacValues
    * Fix: AM wave gen calculation
    * Older/wrong AM wave data replaced with newer ones. Some deleted.
    * Documentation update to show the new calculation and other general
    information added.
    * Firmware
    * Now using the corrected values to generate AM.
    * AM wave now 2250 sample points at 1.5x frequency. This change is
    not part of the fix, but done to make `fc/fm` lower making it
    easier to see the AM bands i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
    [feature_test.c, tests.c]
2026-04-06 Fix: burst_pulses_test was actually never called
    [main.c]
2026-04-06 Fix: Mode change did not work in burst pulses test
    Happened because mode change was not checked within the loop within
    long_delay function
    [tests.c]
2026-04-07 Fix: Unittest failures after f3c554d
    [feature_test.c, tests.c]
2026-04-07 Schematic updated to show Burst Pulses test output
    [scopetester.kicad_sch]
